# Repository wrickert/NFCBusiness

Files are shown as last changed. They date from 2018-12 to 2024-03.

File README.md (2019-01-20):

# NFCBusiness
## Overview
In order to stand out to potential employers I wanted to create my own variation on the PCB business card. I wanted my badge to do more than just look intresting. However, batteries are bulky and expensive. With the sheer number of phones equiped with Google pay/apple pay NFC in phones is becoming increasingly common. I think this makes NFC equiped PCB business cards a natural combination.

## RF430
This project uses a clever little chip, the RF430FRL154HCRGER. This chip is a variant on TI's MSP430. This one combines a NFC RF front end with a MSP430. We will be programming with a JTAG header and I will be building an accompanying POGO pin programming jig.

## D6 CharliePlexing Variant
There is a way to use CharliePlexing to drive seven LEDs with only two GPIO. This does not give you control of individual LEDs, but works in convient pairs for displaying dice values.<br>
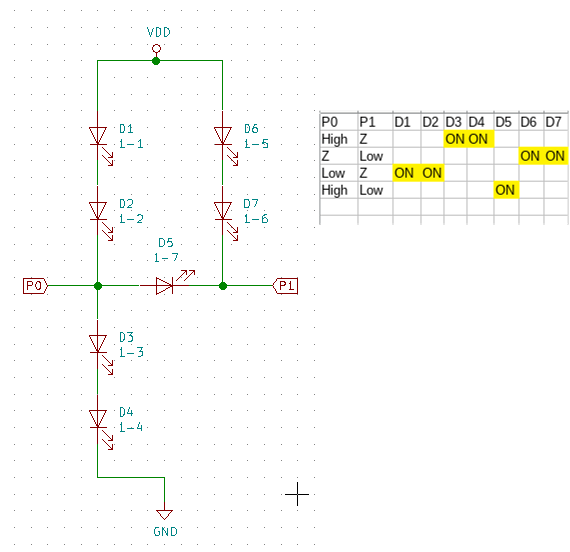
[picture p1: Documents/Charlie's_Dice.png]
Charlie's_Dice


## Programming Jig
Created a programming Jig that uses POGO pins, https://www.digikey.com/product-detail/en/mill-max-manufacturing-corp/0906-0-15-20-76-14-11-0/ED8180-ND <br>
This consists of two different PCBs that can all be stacked to reach the desired result<br>

## Status
1Jan2019 - Completed and ordered version 1<br>
17Jan2019 - IT WORKS! While the antenna leaves much to be desired it is good enough to register on my phone! Need to improve antenna and create programming jig.<br>
18Jan2019 - Fixed issues, created new PCB antenna, ordered version 2<br>
19Jan2019 - Found issue with V2, created V2a. Completed V1 Programming Jig and ordered from JLCPCB.<br>

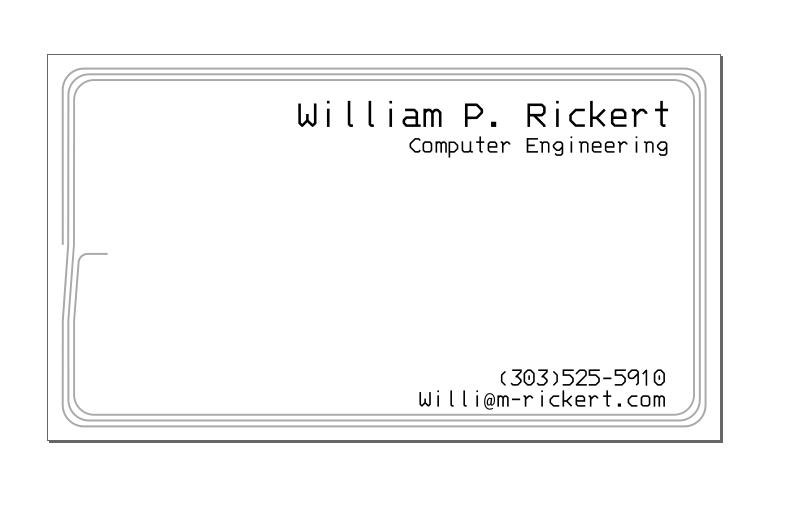
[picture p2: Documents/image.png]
Inkscape image

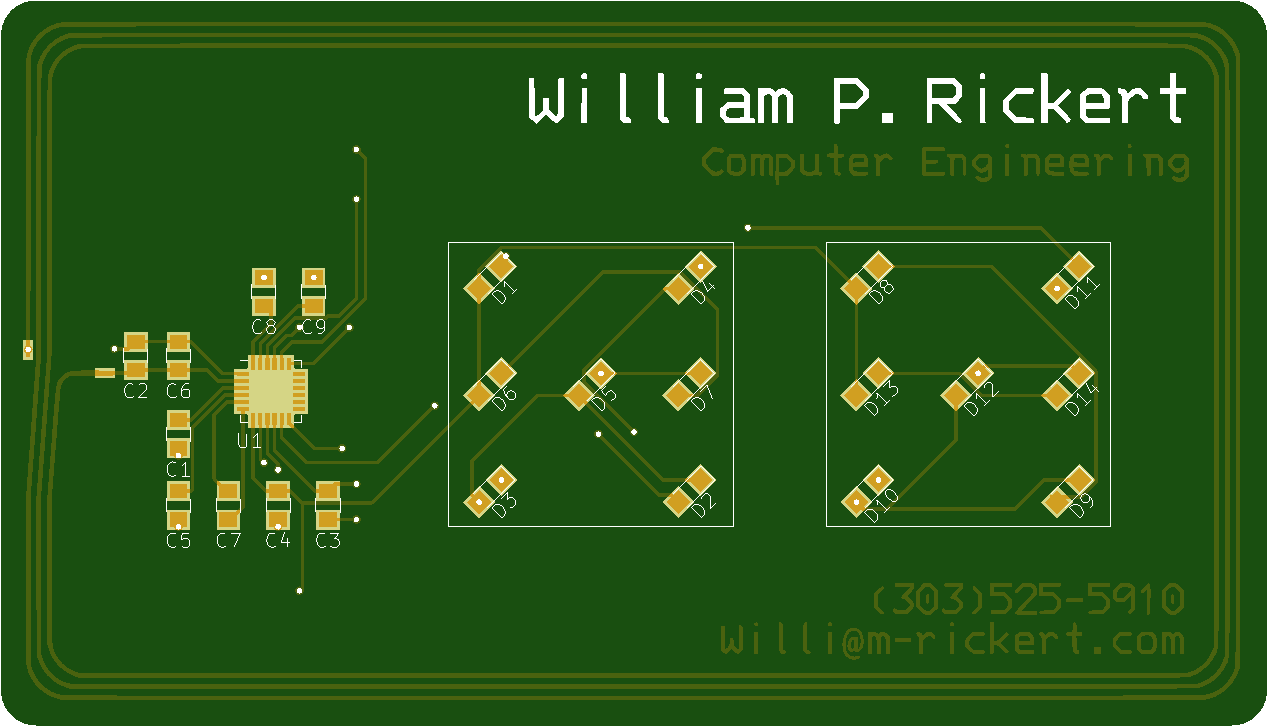
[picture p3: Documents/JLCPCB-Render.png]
JLCPCB Render


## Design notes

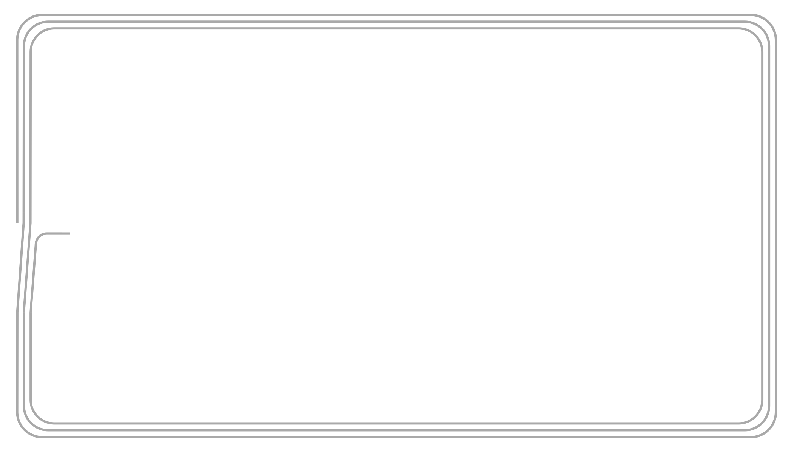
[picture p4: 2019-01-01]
Schematic/.svg2shenzhen-cache/images/F.Cu_g1058.png

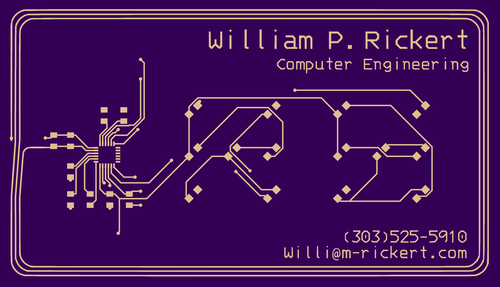
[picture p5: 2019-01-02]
Documents/OSH-Cu.png

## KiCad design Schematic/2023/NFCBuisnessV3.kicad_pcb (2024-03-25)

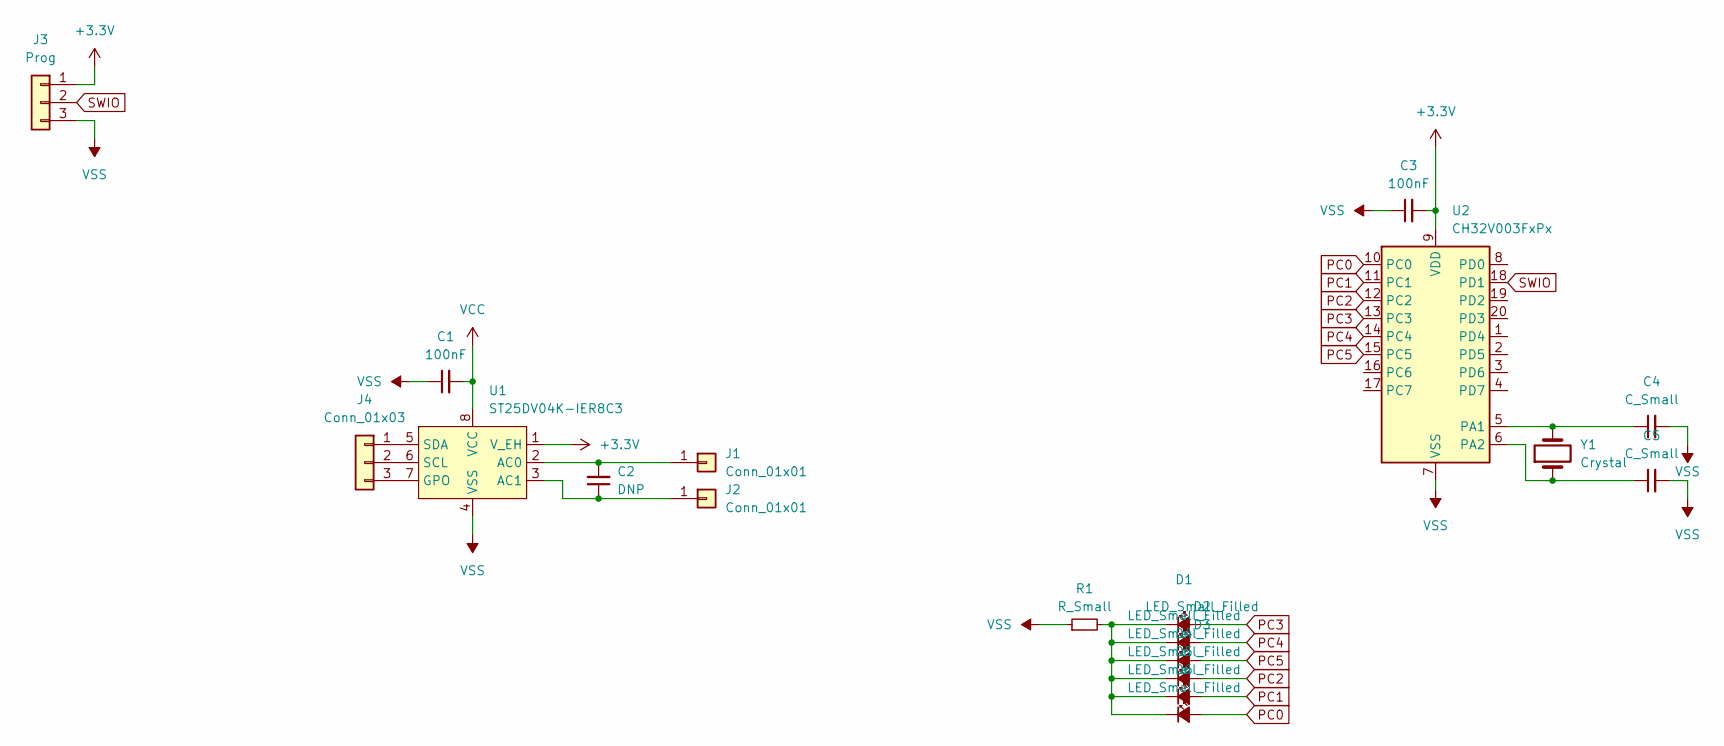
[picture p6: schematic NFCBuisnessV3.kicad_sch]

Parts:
C1, C3: 100nF; C_0805_2012Metric
C2: DNP; C_0805_2012Metric
C4, C5: C_Small; C_0805_2012Metric
D1, D2, D3, D4, D5, D6: LED_Small_Filled; LED_0805_2012Metric
J1, J2: Conn_01x01; NFCadapter
J3: Prog; PinHeader_1x03_P2.54mm_Vertical
J4: Conn_01x03; PinHeader_1x03_P2.54mm_Vertical
R1: R_Small; R_0805_2012Metric
U1: ST25DV04K-IER8C3; TSSOP_K-IER6T3_STM
U2: CH32V003FxPx; TSSOP-20_4.4x6.5mm_P0.65mm
Y1: Crystal; Crystal_SMD_2012-2Pin_2.0x1.2mm_HandSoldering

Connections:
+3.3V: C3.2, J3.1, U1.1 (V_EH), U2.9 (VDD)
unnamed: D1.1 (K), D2.1 (K), D3.1 (K), D4.1 (K), D5.1 (K), D6.1 (K), R1.2
unnamed: C2.2, J1.1, U1.2 (AC0)
unnamed: C2.1, J2.1, U1.3 (AC1)
unnamed: J4.1, U1.5 (SDA)
unnamed: J4.2, U1.6 (SCL)
unnamed: J4.3, U1.7 (GPO)
unnamed: C4.1, U2.5 (PA1), Y1.2
unnamed: C5.1, U2.6 (PA2), Y1.1
PC0: D6.2 (A), U2.10 (PC0)
PC1: D5.2 (A), U2.11 (PC1)
PC2: D4.2 (A), U2.12 (PC2)
PC3: D1.2 (A), U2.13 (PC3)
PC4: D2.2 (A), U2.14 (PC4)
PC5: D3.2 (A), U2.15 (PC5)
SWIO: J3.2, U2.18 (PD1)
VCC: C1.2, U1.8 (VCC)
VSS: C1.1, C3.1, C4.2, C5.2, J3.3, R1.1, U1.4 (VSS), U2.7 (VSS)

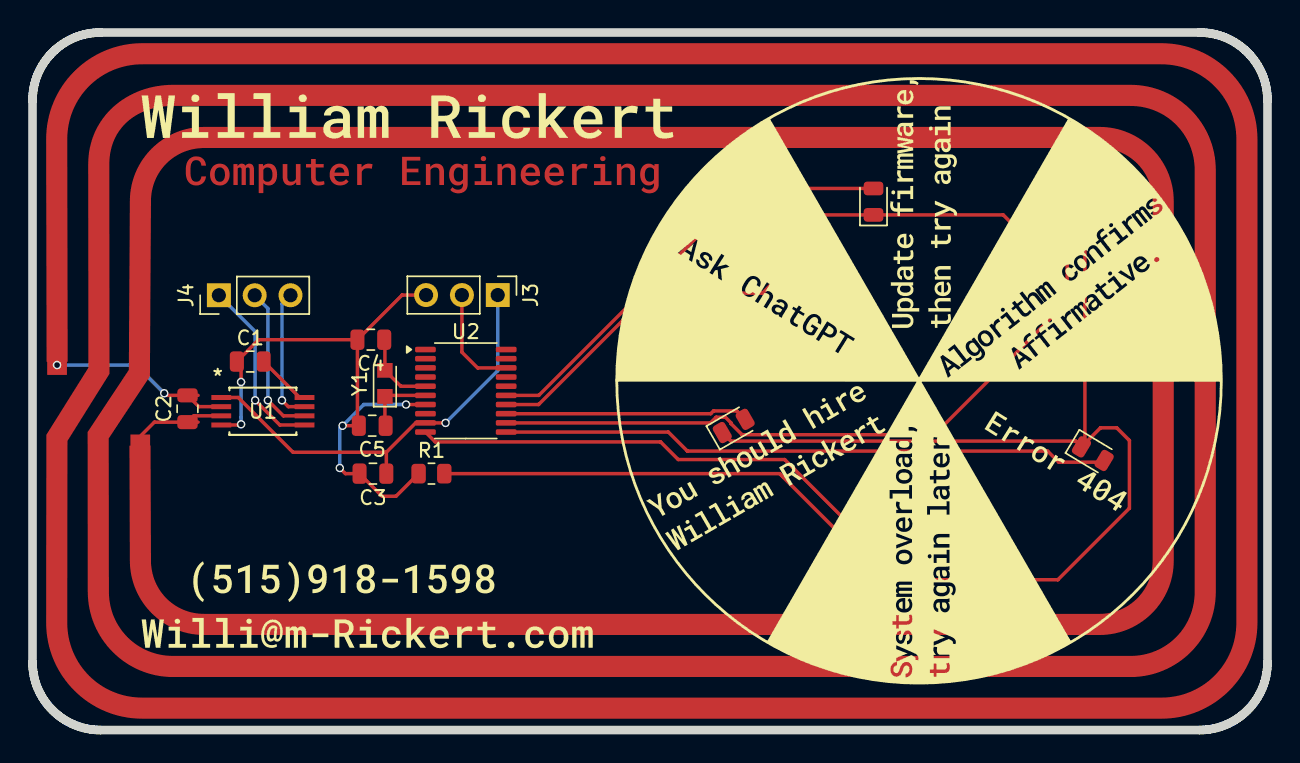
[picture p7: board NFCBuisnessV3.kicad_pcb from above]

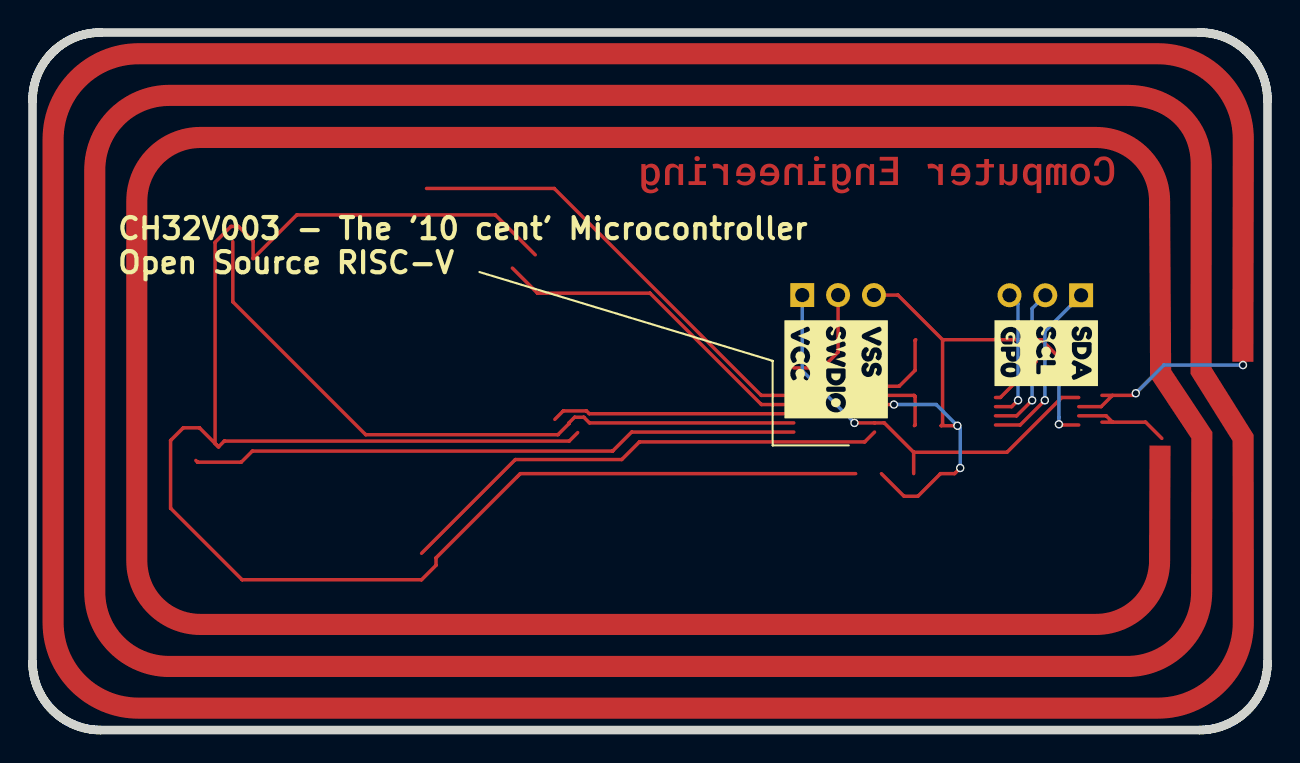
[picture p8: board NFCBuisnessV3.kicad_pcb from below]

Board: 2 copper layers, 87.6 x 49.5 mm, 21 parts (2 on the bottom side), 18 nets.

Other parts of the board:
kibuzzard-65E89835: G***; kibuzzard-65E89835
kibuzzard-65F9F6C6: G***; kibuzzard-65F9F6C6

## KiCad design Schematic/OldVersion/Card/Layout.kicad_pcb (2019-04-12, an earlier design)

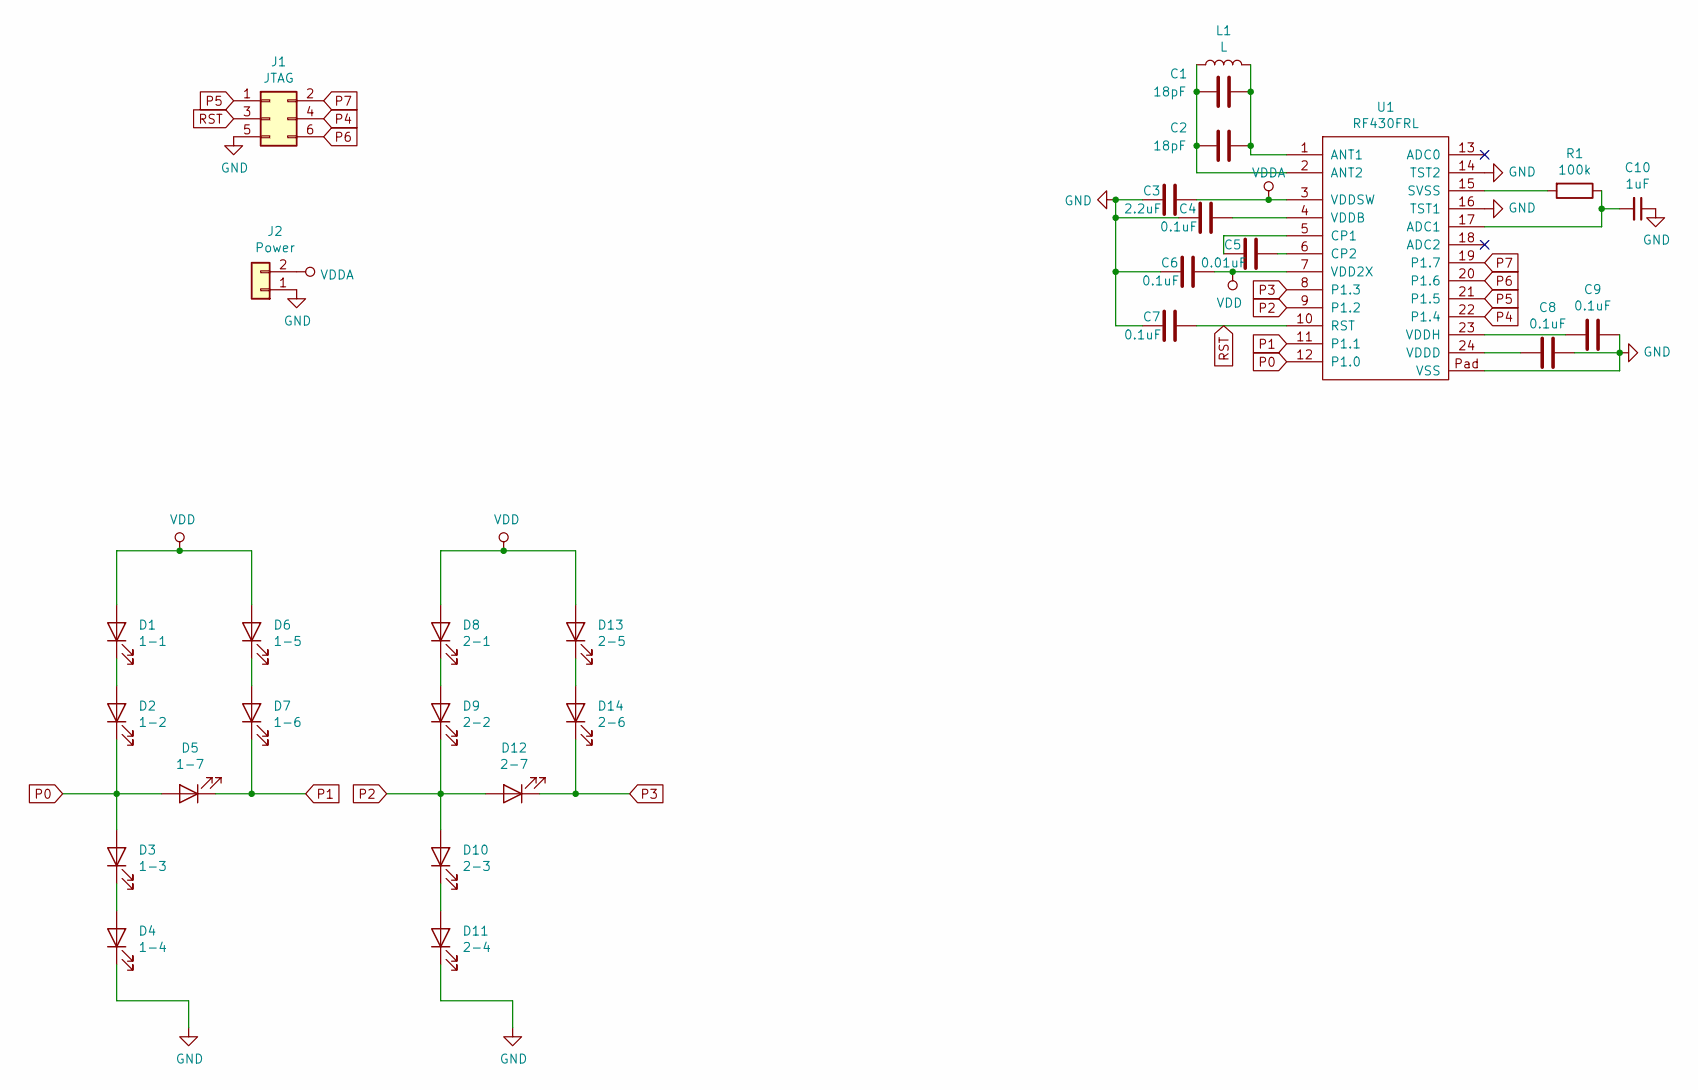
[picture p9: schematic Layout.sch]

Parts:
C1, C2: 18pF; C_0805
C3: 2.2uF; C_0805
C4, C6, C7, C8, C9: 0.1uF; C_0805
C5: 0.01uF; C_0805
C10: 1uF; C_0805
D1: 1-1; LED_0805
D2: 1-2; LED_0805
D3: 1-3; LED_0805
D4: 1-4; LED_0805
D5: 1-7; LED_0805
D6: 1-5; LED_0805
D7: 1-6; LED_0805
D8: 2-1; LED_0805
D9: 2-2; LED_0805
D10: 2-3; LED_0805
D11: 2-4; LED_0805
D12: 2-7; LED_0805
D13: 2-5; LED_0805
D14: 2-6; LED_0805
J1: JTAG; Jtag
J2: Power; PwrPins
L1: L; Layout
R1: 100k; R_0805
U1: RF430FRL; QFN-24-1EP_4x4mm_Pitch0.5mm

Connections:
GND: C3.2, C4.2, C6.2, C7.2, C8.1, C9.1, C10.1, D4.1 (K), D11.1 (K), J1.5, J2.1, U1.14 (TST2), U1.16 (TST1), U1.25, U1.Pad (VSS)
unnamed 1: C1.1, C2.1, L1.2, U1.1 (ANT1); also elsewhere on the board
unnamed 2: C1.2, C2.2, L1.1, U1.2 (ANT2); also elsewhere on the board
unnamed: C4.1, U1.4 (VDDB)
unnamed: C5.1, U1.6 (CP2)
unnamed: C5.2, U1.5 (CP1)
unnamed: C8.2, U1.24 (VDDD)
unnamed: C9.2, U1.23 (VDDH)
unnamed: C10.2, R1.1, U1.17 (ADC1)
unnamed: D1.1 (K), D2.2 (A)
unnamed: D3.1 (K), D4.2 (A)
unnamed: D6.1 (K), D7.2 (A)
unnamed: D8.1 (K), D9.2 (A)
unnamed: D10.1 (K), D11.2 (A)
unnamed: D13.1 (K), D14.2 (A)
unnamed: R1.2, U1.15 (SVSS)
P0: D2.1 (K), D3.2 (A), D5.2 (A), U1.12 (P1.0)
P1: D5.1 (K), D7.1 (K), U1.11 (P1.1)
P2: D9.1 (K), D10.2 (A), D12.2 (A), U1.9 (P1.2)
P3: D12.1 (K), D14.1 (K), U1.8 (P1.3)
P4: J1.4, U1.22 (P1.4)
P5: J1.1, U1.21 (P1.5)
P6: J1.6, U1.20 (P1.6)
P7: J1.2, U1.19 (P1.7)
RST: C7.1, J1.3, U1.10 (RST)
VDD: C6.1, D1.2 (A), D6.2 (A), D8.2 (A), D13.2 (A), U1.7 (VDD2X)
VDDA: C3.1, J2.2, U1.3 (VDDSW)

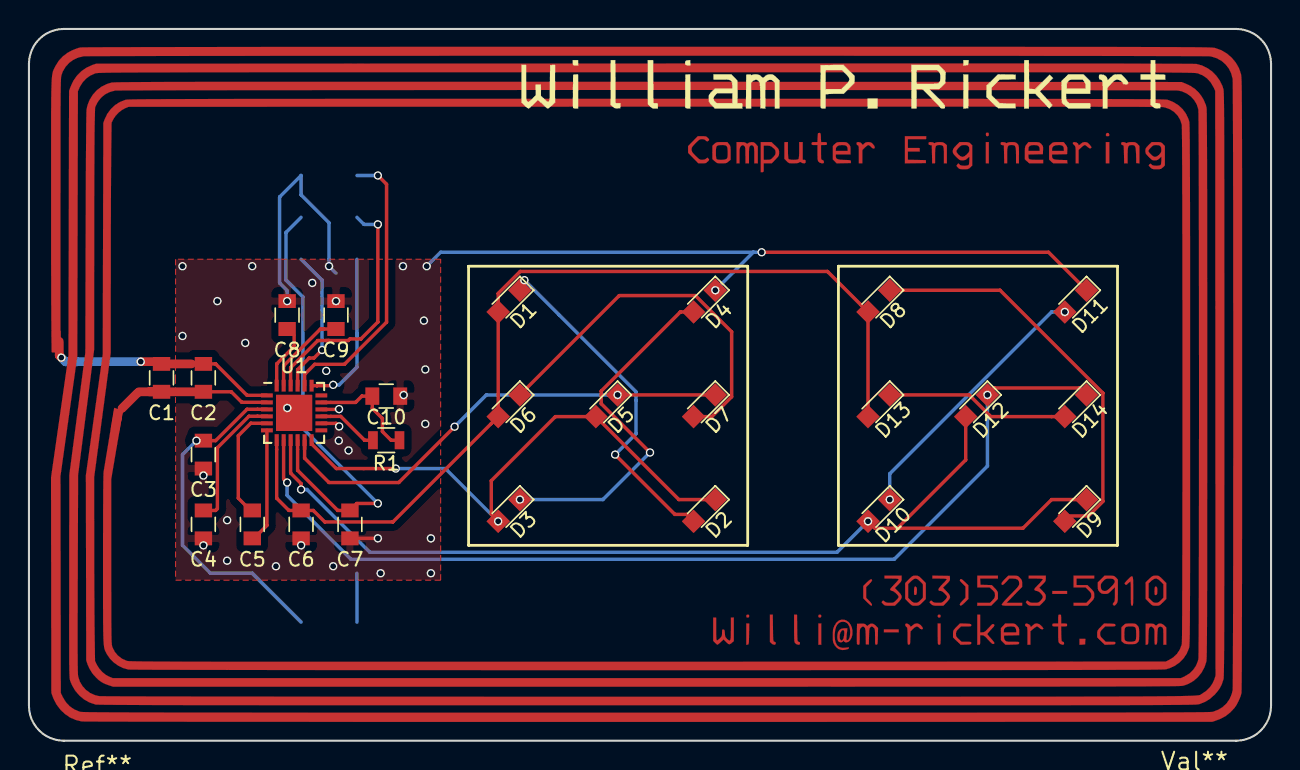
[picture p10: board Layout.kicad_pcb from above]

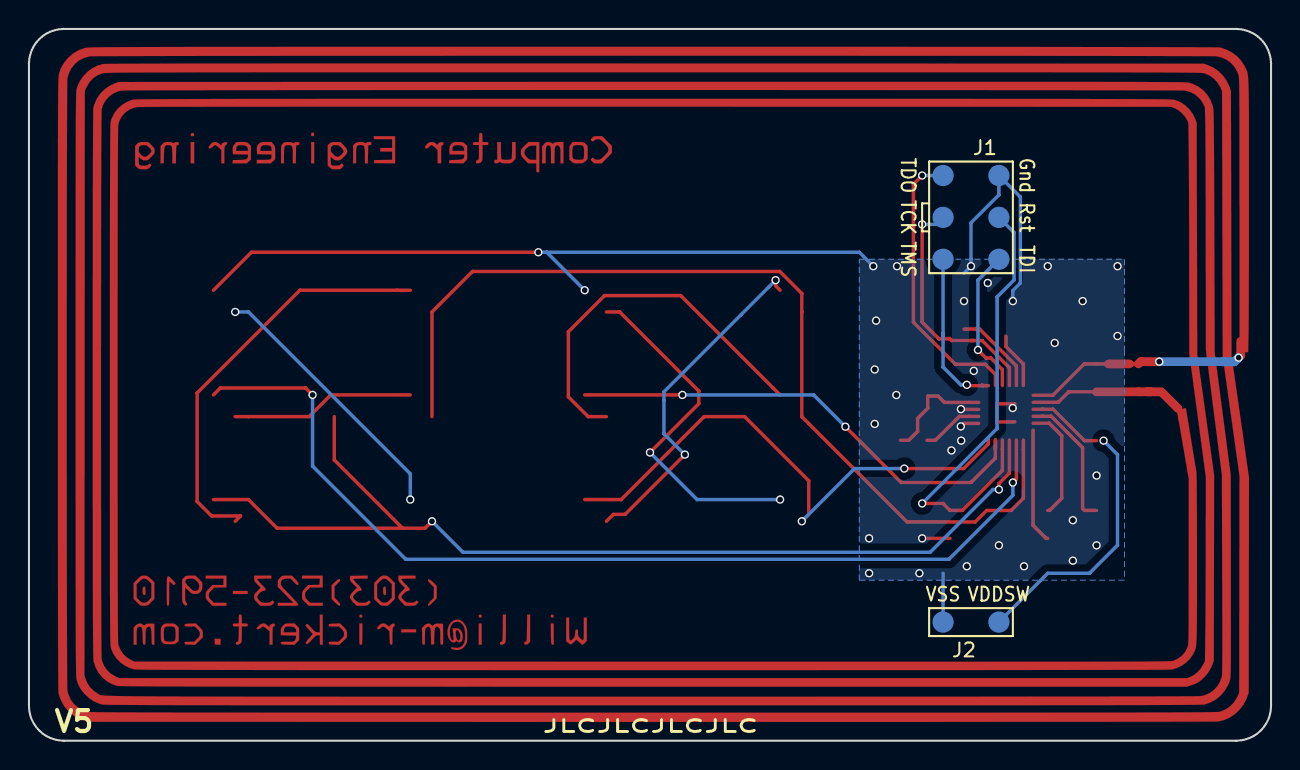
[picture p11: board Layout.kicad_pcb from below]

Board: 2 copper layers, 89.0 x 51.0 mm, 29 parts (2 on the bottom side), 27 nets.

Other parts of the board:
Ref**: Val**; Layout-v2

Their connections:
unnamed 1: Ref**.1; also elsewhere on the board
unnamed 2: Ref**.2; also elsewhere on the board

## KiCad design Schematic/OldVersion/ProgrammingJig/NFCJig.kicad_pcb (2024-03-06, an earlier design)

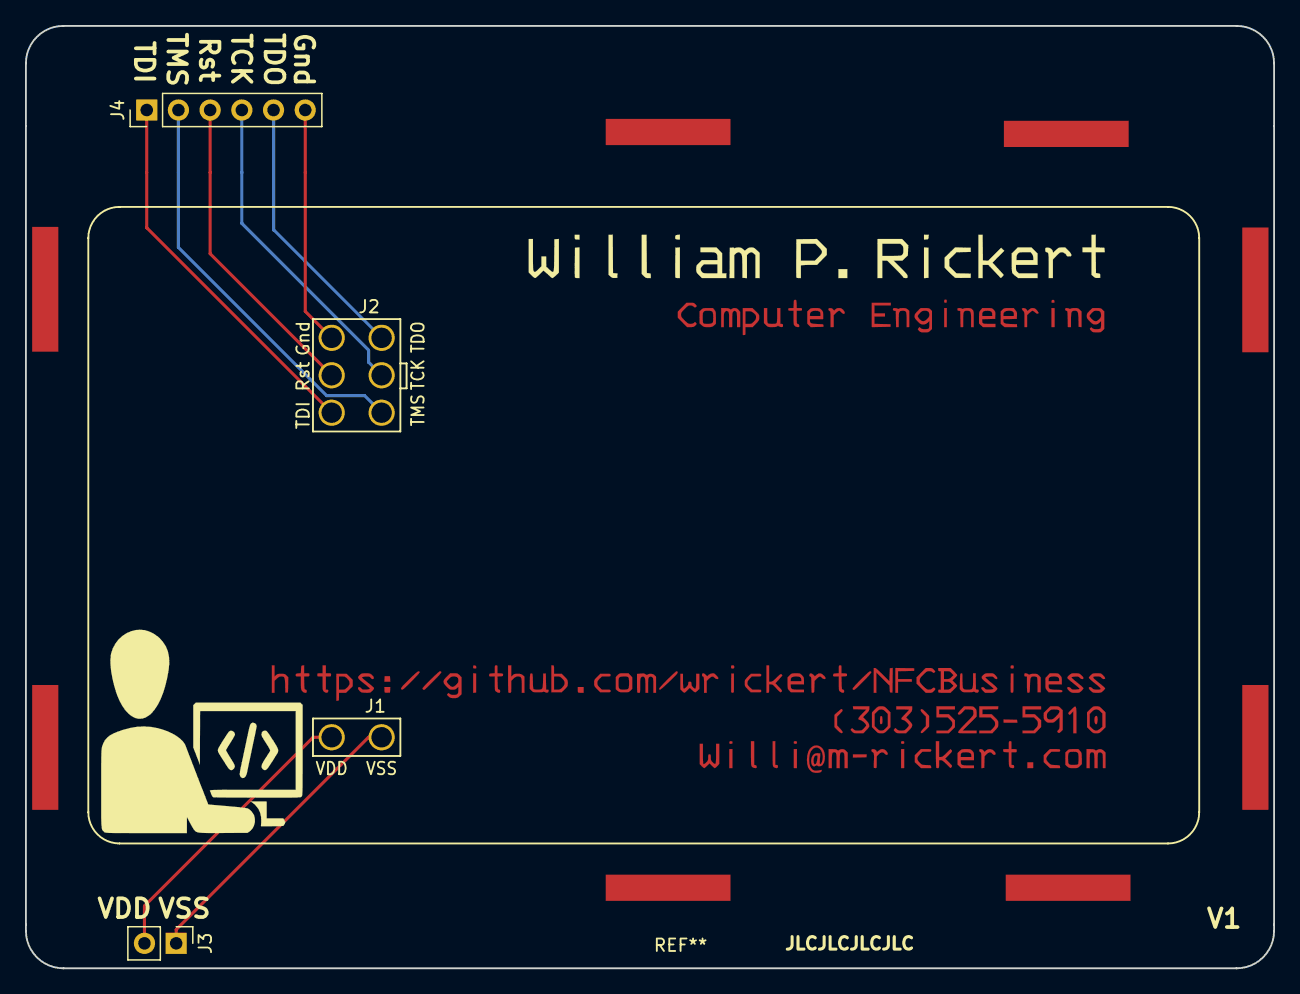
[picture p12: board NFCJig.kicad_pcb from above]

Board: 2 copper layers, 100.0 x 75.5 mm, 4 parts (0 on the bottom side), 8 nets.

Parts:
J1: Power; PogoPwr
J2: JTAG; PogoJTAG
J3: Power; Pin_Header_Straight_1x02_Pitch2.54mm
J4: JTAG; Pin_Header_Straight_1x06_Pitch2.54mm

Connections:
unnamed: J1.1, J3.1
unnamed: J1.2, J3.2
unnamed: J2.1, J4.1
unnamed: J2.2, J4.2
unnamed: J2.3, J4.3
unnamed: J2.4, J4.4
unnamed: J2.5, J4.6
unnamed: J2.6, J4.5

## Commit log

2018-12-23 Started project
    [NFCBusiness .kicad_pcb, NFCBusiness .sch, _saved_NFCBusiness .sch]
2019-01-01 Antenna completed, working on schematics. About to begin programming jig
    [Layout.kicad_pcb, Layout.sch, NFCBusiness .kicad_pcb]
2019-01-01 Changing computers
    [NFCJig.kicad_pcb, NFCJig.sch]
2019-01-02 Finished and ordered V1
    [Layout-B.Cu.gbr, Layout-B.Mask.gbr, Layout-B.SilkS.gbr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]
2019-01-07 Added JLC customer id location
    [Layout.kicad_pcb]
2019-01-08 Changed programming footprint to use VDDSW
    [Layout.kicad_pcb, Layout.sch]
2019-01-19 Changed pcb antenna to match proper inductance
    [Layout-B.Cu.gbr, Layout-B.Mask.gbr, Layout-B.SilkS.gbr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]
2019-01-19 Played with graphics
    [Layout-B.Cu.gbr, Layout-B.Mask.gbr, Layout-B.SilkS.gbr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]
2019-01-19 Fixed ground issue and cleaned up board
    [Layout-B.Cu.gbr, Layout-B.Mask.gbr, Layout-B.SilkS.gbr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]
2019-01-19 Completed and ordered programming jig
    [NFCJig-B.Cu.gbr, NFCJig-B.Mask.gbr, NFCJig-B.SilkS.gbr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]
2019-02-20 V3, changes may improve reading distance
    [Layout-B.Cu.gbr, Layout-B.Mask.gbr, Layout-B.SilkS.gbr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]
2019-02-20 Removed drill file
    [Layout.drl]
2019-04-12 Added better ground plane
    [Layout-B.Cu.gbr, Layout-B.Mask.gbr, Layout-B_Cu.gbr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]
2024-03-06 Updated to 2023 info
    [Layout-B.Cu.gbr, Layout-B.Mask.gbr, Layout-B.SilkS.gbr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]
2024-03-19 Updated for V2
    [NFCBuisnessV3-B_Cu.gbr, NFCBuisnessV3-B_Mask.gbr, NFCBuisnessV3-B_Silkscreen.gbr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]
2024-03-25 Ordered 2024 V2
    [NFCBuisnessV3-B_Cu.gbr, NFCBuisnessV3-B_Mask.gbr, NFCBuisnessV3-B_Silkscreen.gbr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]
